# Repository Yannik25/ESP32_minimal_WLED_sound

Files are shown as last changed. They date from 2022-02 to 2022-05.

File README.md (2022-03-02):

# ESP32_minimal_WLED_sound

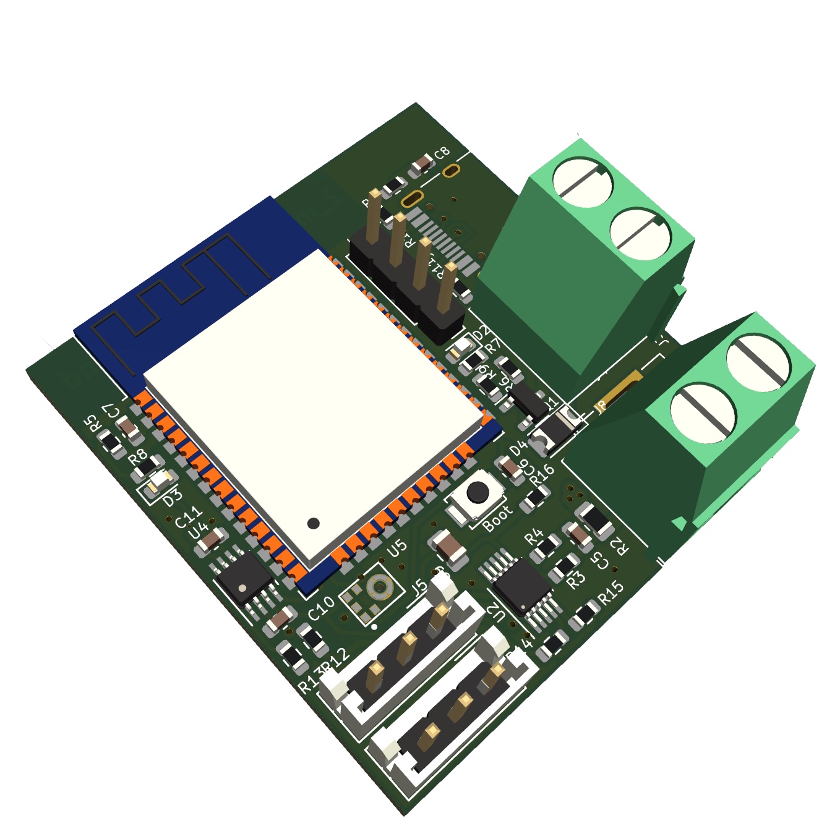
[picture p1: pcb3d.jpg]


 Either install WLED and configure Digital LEDs on GPIO 2 and 4 with following functions:
 - 2 channels for Digital LEDs
 - 1 mosfet switch output
 - sound reactive with microphone
 
 or install ESPHome to have full support of following:
 - 2 channels for Digital LEDs
 - 1 mosfet switch output
 - INA226 current sensing

# ESPHome ESP32 Sound Module WebInstaller

ESPHome Configuration:

It includes a GitHub workflow that will automatically build the configuration(s) and then deploys a simple 
website via GitHub pages that utilises [ESP Web Tools](https://esphome.github.io/esp-web-tools/) for users to 
easily install your project onto their device.

## Instructions
Open: [https://yannik25.github.io/ESP32_minimal_WLED_sound/](https://yannik25.github.io/ESP32_minimal_WLED_sound/) and follow instructions.

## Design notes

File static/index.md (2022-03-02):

# About

ESPHome Configuration for ESP32 Digital LED Sound reactive module
<center>
    image of esp32 module
</center>

# Installation

You can use the button below to install the pre-built firmware directly to your device via USB from the browser.

<esp-web-install-button manifest="./manifest.json"></esp-web-install-button>

<script type="module" src="https://unpkg.com/esp-web-tools@5.2.0/dist/web/install-button.js?module"></script>

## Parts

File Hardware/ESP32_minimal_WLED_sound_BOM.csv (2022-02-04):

Comment | Designator | Footprint | LCSC
100nF | C1 C2 C3 C4 C9 | Capacitor_SMD:C_0805_2012Metric
100nF | C5 C6 C7 C8 C10 C11 | Capacitor_SMD:C_0603_1608Metric
LED | D2 D3 | LED_SMD:LED_0603_1608Metric
1N4148 | D4 | Diode_SMD:D_1206_3216Metric
USB_C_Receptacle_USB2.0 | J2 | Connector_USB:USB_C_Receptacle_HRO_TYPE-C-31-M-12 | C165948
ICS-43434 | MK1 | ICS-43434:MIC_ICS-43434
AO3400A | Q1 | Package_TO_SOT_SMD:SOT-23
1M | R1 | Resistor_SMD:R_0603_1608Metric | C163928
5.1k | R10 R11 | Resistor_SMD:R_0603_1608Metric | C163928
300 | R12 R13 | Resistor_SMD:R_0603_1608Metric
4 | 7k | R14 R15 | Resistor_SMD:R_0603_1608Metric
0.01 | R2 | Resistor_SMD:R_0805_2012Metric
10 | R3 R4 | Resistor_SMD:R_0603_1608Metric
10k | R5 R7 | Resistor_SMD:R_0603_1608Metric | C99198
1k | R6 | Resistor_SMD:R_0603_1608Metric
100 | R8 | Resistor_SMD:R_0603_1608Metric | C22775
150 | R9 | Resistor_SMD:R_0603_1608Metric
Boot | SW2 | Button_Switch_SMD:SW_SPST_B3U-1000P-B | C115357
LM1117-5 | U1 | Package_TO_SOT_SMD:SOT-223
INA226 | U2 | Package_SO:VSSOP-10_3x3mm_P0.5mm
LM1117-3.3 | U3 | Package_TO_SOT_SMD:SOT-223
TXS0102DCT | U4 | Package_SO:SSOP-8_2.95x2.8mm_P0.65mm
ESP32-WROOM-32 | U5 | RF_Module:ESP32-WROOM-32

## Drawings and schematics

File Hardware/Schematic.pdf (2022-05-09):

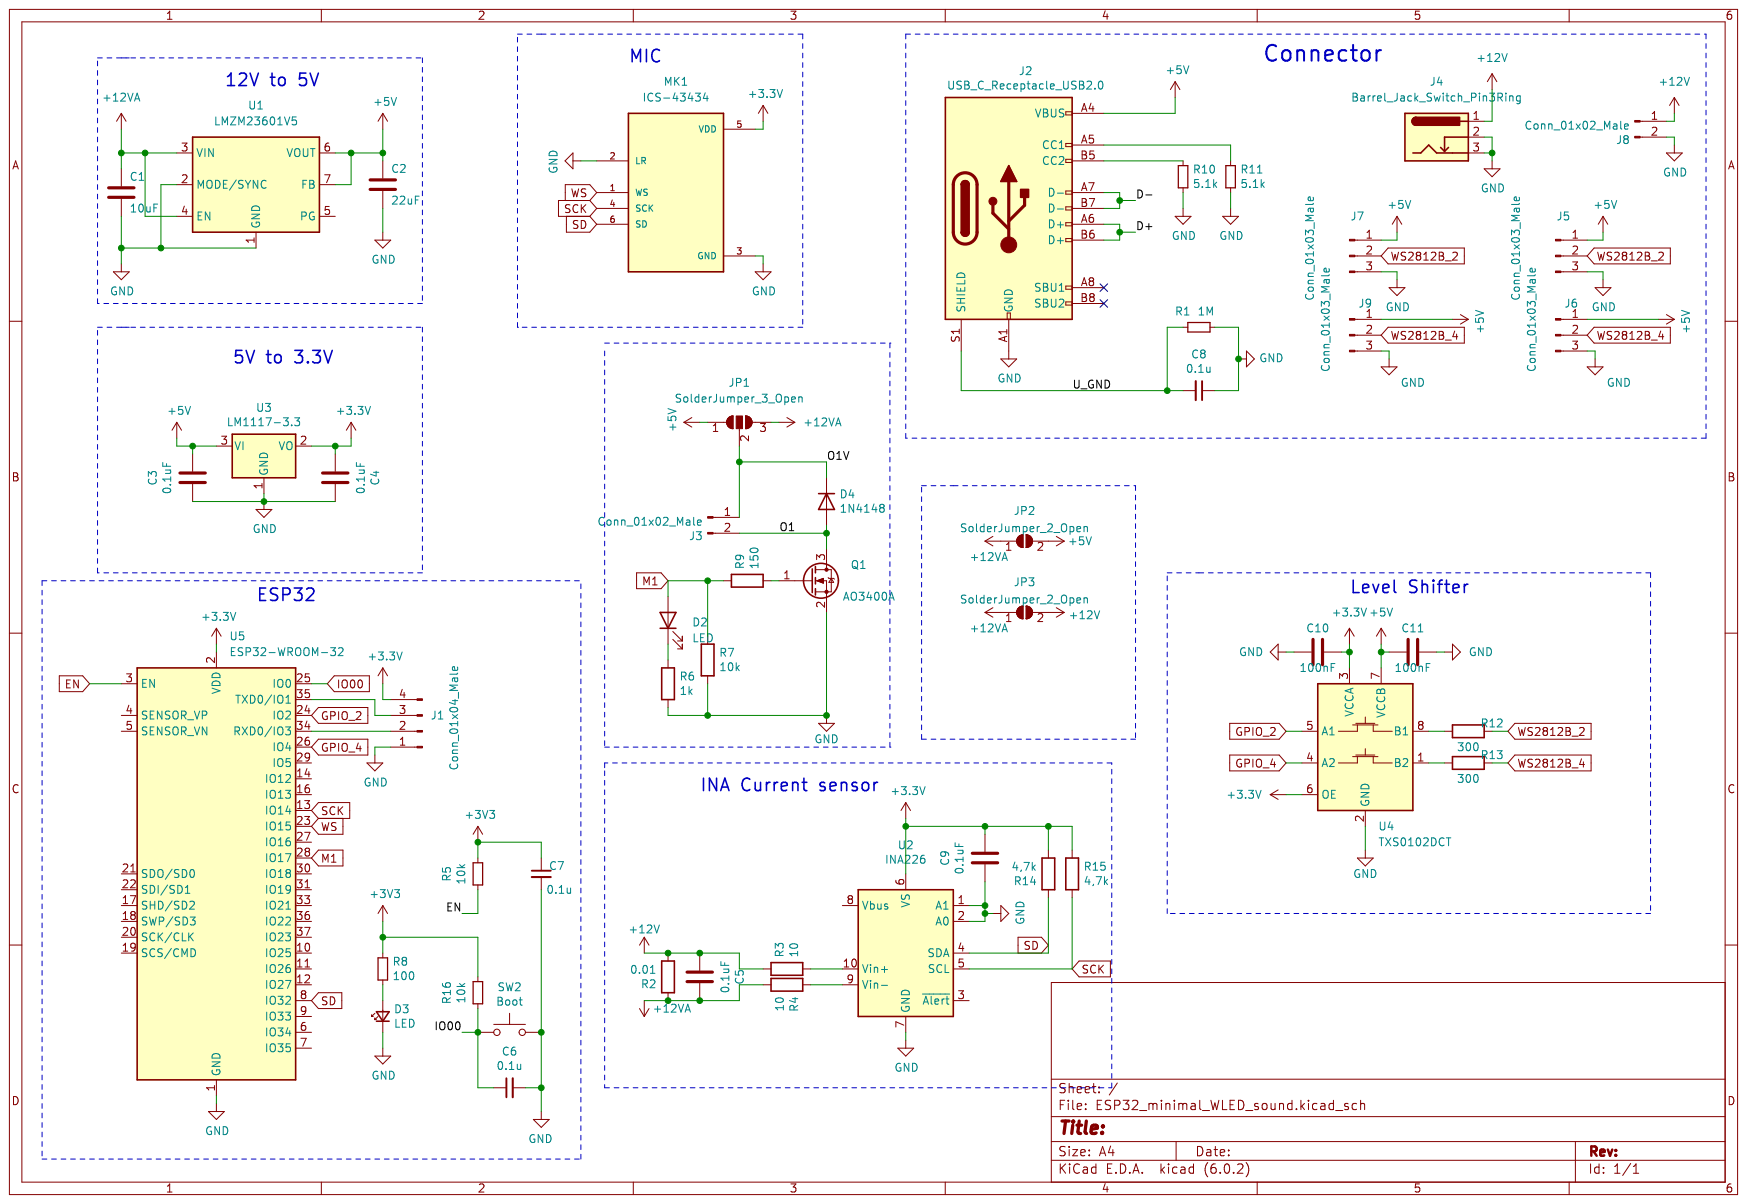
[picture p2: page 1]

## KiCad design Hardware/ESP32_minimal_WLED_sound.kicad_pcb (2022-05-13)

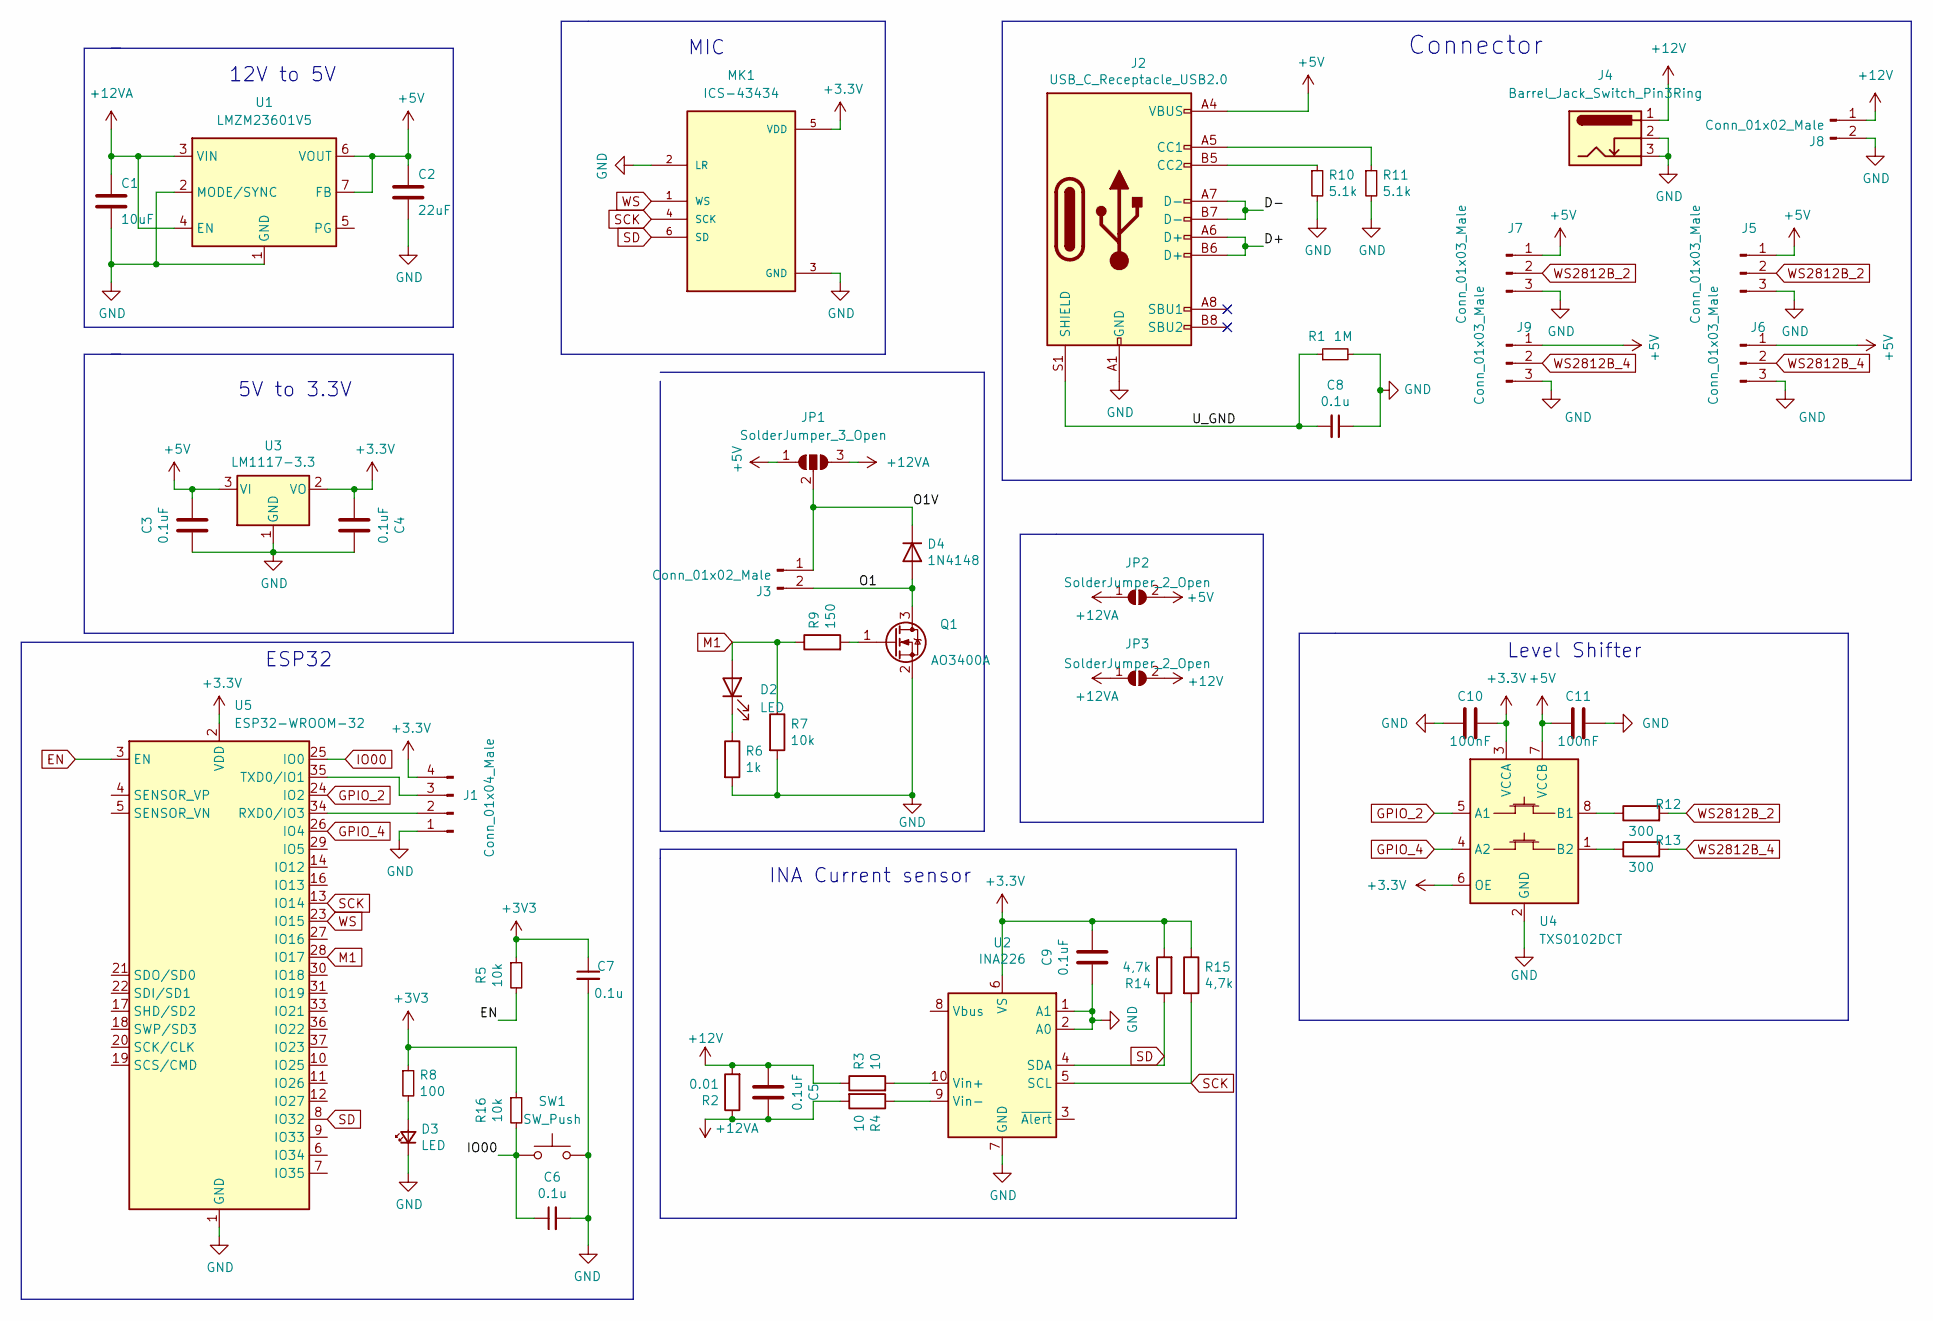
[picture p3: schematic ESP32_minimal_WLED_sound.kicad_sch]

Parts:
C1: 10uF; C_0603_1608Metric
C2: 22uF; C_0805_2012Metric
C3, C4, C9: 0.1uF; C_0805_2012Metric
C5: 0.1uF; C_0603_1608Metric
C6, C7, C8: 0.1u; C_0603_1608Metric; LCSC C14663
C10, C11: 100nF; C_0603_1608Metric
D2: LED; LED_0603_1608Metric
D3: LED; LED_0603_1608Metric; LCSC C205445
D4: 1N4148; D_1206_3216Metric
J1: Conn_01x04_Male; PinHeader_1x04_P2.54mm_Vertical
J2: USB_C_Receptacle_USB2.0; USB_C_Receptacle_HRO_TYPE-C-31-M-12; LCSC C165948
J3, J8: Conn_01x02_Male; TerminalBlock_Phoenix_MKDS-1,5-2-5.08_1x02_P5.08mm_Horizont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
J4: Barrel_Jack_Switch_Pin3Ring; BarrelJack_GCT_DCJ200-10-A_Horizontal
J5, J6: Conn_01x03_Male; JST_EH_B3B-EH-A_1x03_P2.50mm_Vertical
J7, J9: Conn_01x03_Male; PinHeader_1x03_P2.54mm_Vertical
JP1: SolderJumper_3_Open; SolderJumper-3_P1.3mm_Open_Pad1.0x1.5mm
JP2, JP3: SolderJumper_2_Open; SolderJumper-2_P1.3mm_Open_Pad1.0x1.5mm
MK1: ICS-43434; MIC_ICS-43434
Q1: AO3400A; SOT-23
R1: 1M; R_0603_1608Metric; LCSC C163928
R2: 0.01; R_0805_2012Metric
R3, R4: 10; R_0603_1608Metric
R5, R16: 10k; R_0603_1608Metric; LCSC C99198
R6: 1k; R_0603_1608Metric
R7: 10k; R_0603_1608Metric
R8: 100; R_0603_1608Metric; LCSC C22775
R9: 150; R_0603_1608Metric
R10, R11: 5.1k; R_0603_1608Metric; LCSC C163928
R12, R13: 300; R_0603_1608Metric
R14, R15: 4,7k; R_0603_1608Metric
SW1: SW_Push; SW_Push_SPST_NO_Alps_SKRK
U1: LMZM23601V5; Texas_SIL0010A_MicroSiP-10-1EP_3.8x3mm_P0.6mm_EP0.7x2.9mm_T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
U2: INA226; VSSOP-10_3x3mm_P0.5mm
U3: LM1117-3.3; SOT-223
U4: TXS0102DCT; SSOP-8_2.95x2.8mm_P0.65mm
U5: ESP32-WROOM-32

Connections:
+5V: C2.1, C3.1, C11.1, J2.A4 (VBUS), J2.A9 (VBUS), J2.B4 (VBUS), J2.B9 (VBUS), J5.1, J6.1, J7.1, J9.1, JP1.1 (A), JP2.2 (B), U1.6 (VOUT), U1.7 (FB), U3.3 (VI), U4.7 (VCCB)
+12V: C5.2, J4.1, J8.1, JP3.2 (B), R2.2, R3.1
+12VA: C1.1, C5.1, JP1.3 (B), JP2.1 (A), JP3.1 (A), R2.1, R4.2, U1.3 (VIN), U1.4 (EN)
/D+: J2.A6 (D+), J2.B6 (D+)
/D-: J2.A7 (D-), J2.B7 (D-)
/O1: D4.2 (A), J3.2, Q1.3 (D)
/O1V: D4.1 (K), J3.1, JP1.2 (C)
/U_GND: C8.2, J2.S1 (SHIELD), R1.1
EN: R5.2, U5.3 (EN)
GND: C1.2, C2.2, C3.2, C4.1, C6.2, C7.2, C8.1, C9.2, C10.1, C11.2, D3.1 (K), J1.1, J2.A1 (GND), J2.A12 (GND), J2.B1 (GND), J2.B12 (GND), J4.2, J4.3, J5.3, J6.3, J7.3, J8.2, J9.3, MK1.2 (LR), MK1.3 (GND), Q1.2 (S), R1.2, R6.2, R7.2, R10.2, R11.2, SW1.2, U1.1 (GND), U1.2 (MODE/SYNC), U1.11 (GND), U2.1 (A1), U2.2 (A0), U2.7 (GND), U3.1 (GND), U4.2 (GND), U5.1 (GND), U5.15 (GND), U5.38 (GND), U5.39 (GND)
GPIO_2: U4.5 (A1), U5.24 (IO2)
GPIO_4: U4.4 (A2), U5.26 (IO4)
IO00: C6.1, R16.2, SW1.1, U5.25 (IO0)
M1: D2.2 (A), R7.1, R9.1, U5.28 (IO17)
unnamed: D2.1 (K), R6.1
unnamed: D3.2 (A), R8.2
unnamed: J1.2, U5.34 (RXD0/IO3)
unnamed: J1.3, U5.35 (TXD0/IO1)
unnamed: J2.A5 (CC1), R11.1
unnamed: J2.B5 (CC2), R10.1
unnamed: Q1.1 (G), R9.2
unnamed: R3.2, U2.10 (Vin+)
unnamed: R4.1, U2.9 (Vin-)
unnamed: R12.1, U4.8 (B1)
unnamed: R13.1, U4.1 (B2)
SCK: MK1.4 (SCK), R15.2, U2.5 (SCL), U5.13 (IO14)
SD: MK1.6 (SD), R14.1, U2.4 (SDA), U5.8 (IO32)
WS: MK1.1 (WS), U5.23 (IO15)
WS2812B_2: J5.2, J7.2, R12.2
WS2812B_4: J6.2, J9.2, R13.2

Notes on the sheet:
MIC
Level Shifter
ESP32
Connector
12V to 5V
5V to 3.3V
INA Current sensor

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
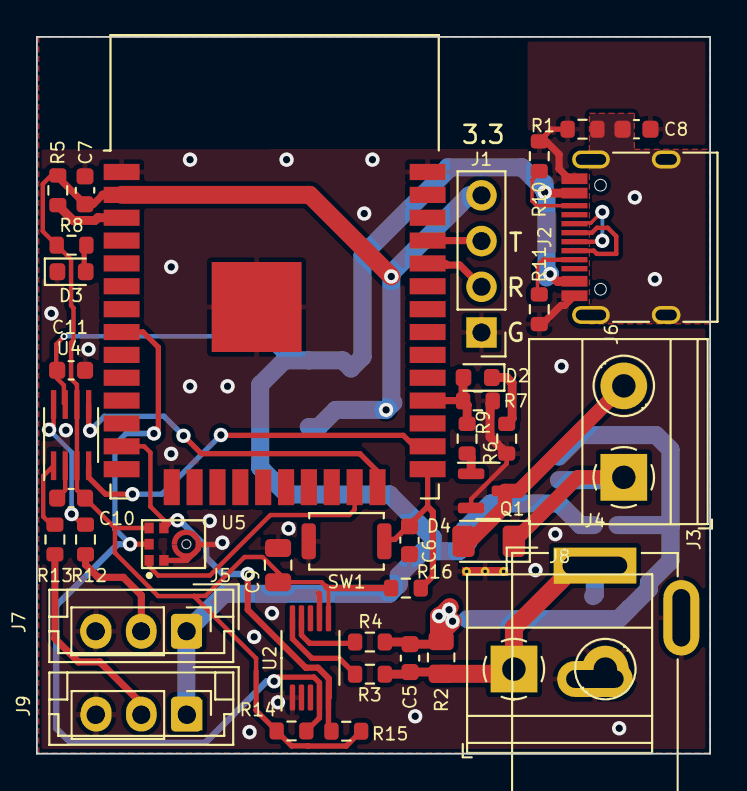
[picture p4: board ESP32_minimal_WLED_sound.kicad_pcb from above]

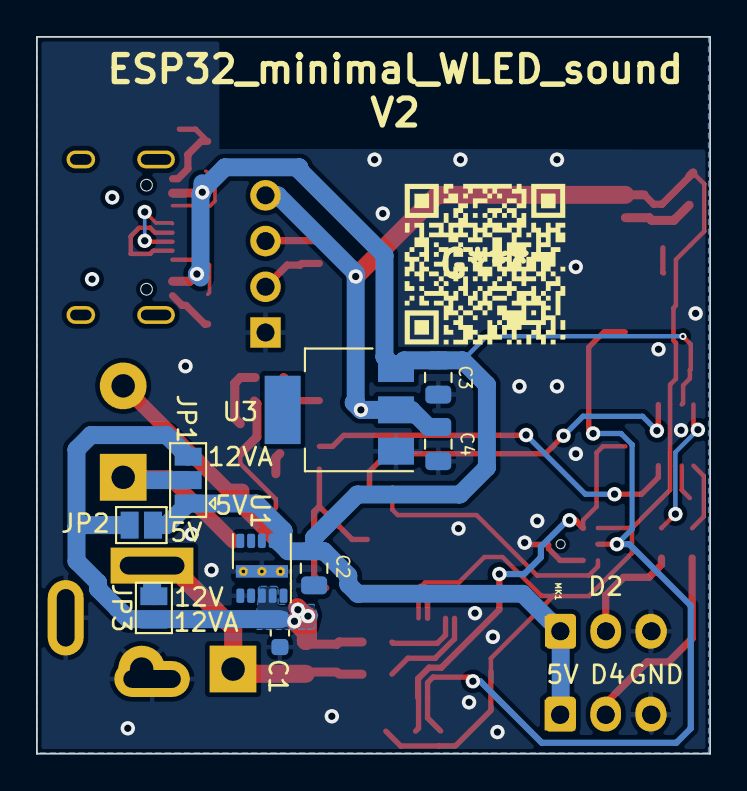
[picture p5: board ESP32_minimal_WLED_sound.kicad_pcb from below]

Board: 2 copper layers, 37.4 x 39.8 mm, 50 parts (9 on the bottom side), 31 nets.

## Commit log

2022-02-03 move files
    [ESP32_minimal_WLED_sound.kicad_pcb, ESP32_minimal_WLED_sound.kicad_sch]
2022-02-04 update to V1
    [ESP32_minimal_WLED_sound.kicad_pcb, ESP32_minimal_WLED_sound.kicad_sch]
2022-02-04 add bom and position files
    [ESP32_minimal_WLED_sound_BOM.csv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]
2022-02-04 fix top position file
    [ESP32_minimal_WLED_sound-top-pos.csv]
2022-03-02 fix esp32 EN and IO0, Todo: solder jumper and 12V to 5V
    [ESP32_minimal_WLED_sound.kicad_pcb, ESP32_minimal_WLED_sound.kicad_sch]
2022-03-02 update esphome config
    [ESP32_minimal_WLED_sound.kicad_pcb]
2022-05-09 switch 12V to 5V to DCDC
    [ESP32_minimal_WLED_sound.kicad_pcb, ESP32_minimal_WLED_sound.kicad_sch]
2022-05-13 update button
    [ESP32_minimal_WLED_sound.kicad_pcb, ESP32_minimal_WLED_sound.kicad_sch]
